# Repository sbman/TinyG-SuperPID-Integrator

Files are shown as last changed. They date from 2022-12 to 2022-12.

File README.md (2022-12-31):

# TinyG-SuperPID-Integrator
 A schematic and PCB design to integrate TinyG with SuperPID

# TinyG Settings
$p1                                                                    
[p1frq] pwm frequency               100 Hz
[p1csl] pwm cw speed lo            5000 RPM
[p1csh] pwm cw speed hi           30000 RPM
[p1cpl] pwm cw phase lo           0.833 [0..1]
[p1cph] pwm cw phase hi           0.000 [0..1]
[p1wsl] pwm ccw speed lo           1000 RPM
[p1wsh] pwm ccw speed hi           2000 RPM
[p1wpl] pwm ccw phase lo          0.125 [0..1]
[p1wph] pwm ccw phase hi          0.200 [0..1]
[p1pof] pwm phase off             0.833 [0..1]

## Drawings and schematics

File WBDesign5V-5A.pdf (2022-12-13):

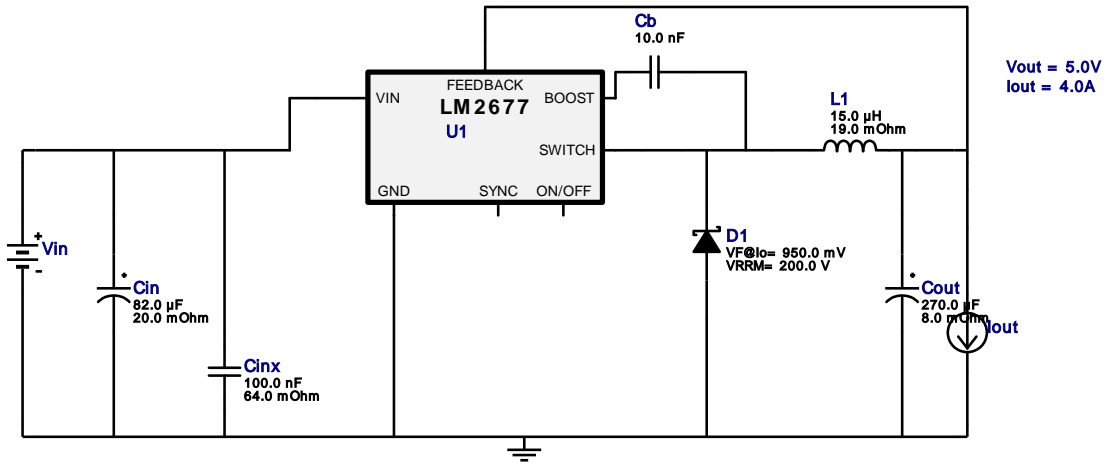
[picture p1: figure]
LM 2 6 7 7 VIN; FEEDBACK; BOOST; SWITCH; GND; SYNC ON/OFF; Cin 82.0 µF 20.0 m Ohm; Cinx 100.0 nF 64.0 m Ohm; Vout = 5.0V Iout = 4.0A; Cout 270.0 µF 8.0 m Ohm; D1 VF@Io= 950.0 m V VRRM= 200.0 V; L1 15.0 µH 19.0 m Ohm; Vin; Iout

Copyright © 2022, Texas Instruments Incorporated | 1 | ti.com/webench

WEBENCH®
Design Report LM2677SX-5.0/NOPB : LM2677SX-5.0/ NOPB 18V-26V to 5.00V @ 4A December 12, 2022 17:42:08 GMT-06:00

## WEBENCH ® Design Report

Design : 14 LM2677SX-5.0/NOPB
LM2677SX-5.0/NOPB 18V-26V to 5.00V @ 4A

VinMin = 18.0V
VinMax = 26.0V
Vout = 5.0V
Iout = 4.0A

Device = LM2677SX-5.0/NOPB Topology = Buck
Created = 2022-12-12 16:49:55.899 BOM Cost = $5.68
BOM Count = 7
Total Pd = 4.2W
1. The small series "trace inductance", particularly from the Switch Output pin, can create a high frequency (10's of MHz) ringing signal at the switch output. If problematic, this ringing can be reduced or eliminated by the use of a series RC damper or snubber network from the switch output to ground. Values of 0.01 uF and 10 ohm are good starting values that may need to be varied depending on the magnitude of parasitic factors in a given design. In an actual end application, these components are normally not required if proper care to minimize trace lengths is taken in the PCB design.

## Electrical BOM

Name | Manufacturer | Part Number | Properties | Qty Price | Footprint
Cb | TDK | CGA4C2C0G1H103J060AA (https://product.tdk.com/en/search/capacitor/ceramic/mlcc/info?part%5Fno%3DCGA4C2C0G1H103J060AA) Series= C0G/NP0 | Cap= 10.0 nF VDC= 50.0 V IRMS= 0.0 A
1 | $0.06
| | | | | 0805 7 mm²
Cin | Panasonic | 35SVPF82M Series= SVPF | Cap= 82.0 uF ESR= 20.0 mOhm VDC= 35.0 V IRMS= 4.0 A
1 | $1.17

CAPSMT_62_E12 106 mm²
Cinx | Kemet | C0805C104M5RACTU (http://capacitoredge.kemet.com/capedge2/DataSheet/Datasheet%2DC0805C104M5RACTU.pdf?pn%3DC0805C104M5RACTU) Series= X7R

Cap= 100.0 nF
ESR= 64.0 mOhm
VDC= 50.0 V
IRMS= 1.64 A

1 $0.01
0805 7 mm²
Cout | Panasonic | 16SVPG270M Series= SVPG | Cap= 270.0 uF ESR= 8.0 mOhm VDC= 16.0 V IRMS= 5.8 A
1 | $0.97

CAPSMT_62_C10 74 mm²
D1 | SMC Diode Solutions | SBRD10200TR (http://www.smc%2Ddiodes.com/propdf/SBRD10200%20N1314%20REV.%2D.pdf) | VF@Io= 950.0 mV VRRM= 200.0 V
1 | $0.18

DPAK 102 mm²

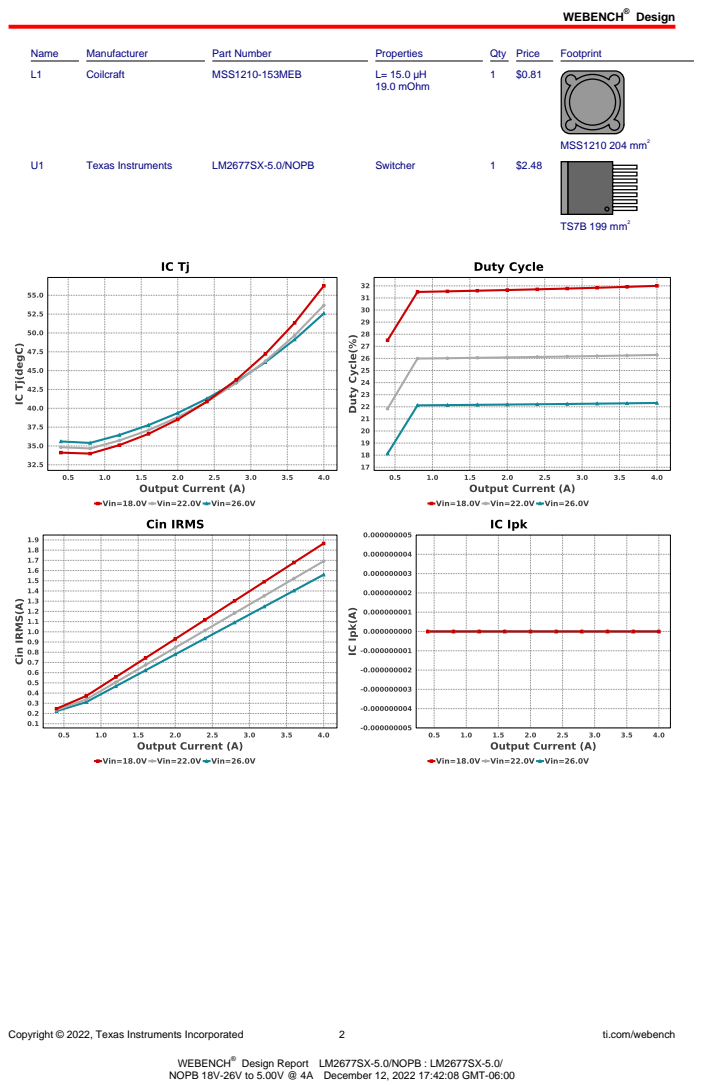
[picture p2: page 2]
Design; Copyright © 2022, Texas Instruments Incorporated; ti.com/webench; Name; Manufacturer; Part Number; Properties; Qty Price; Footprint; Coilcraft; MSS1210-153MEB; 19.0 mOhm; MSS1210 204 mm²; Texas Instruments; LM2677SX-5.0/NOPB; Switcher; TS7B 199 mm²

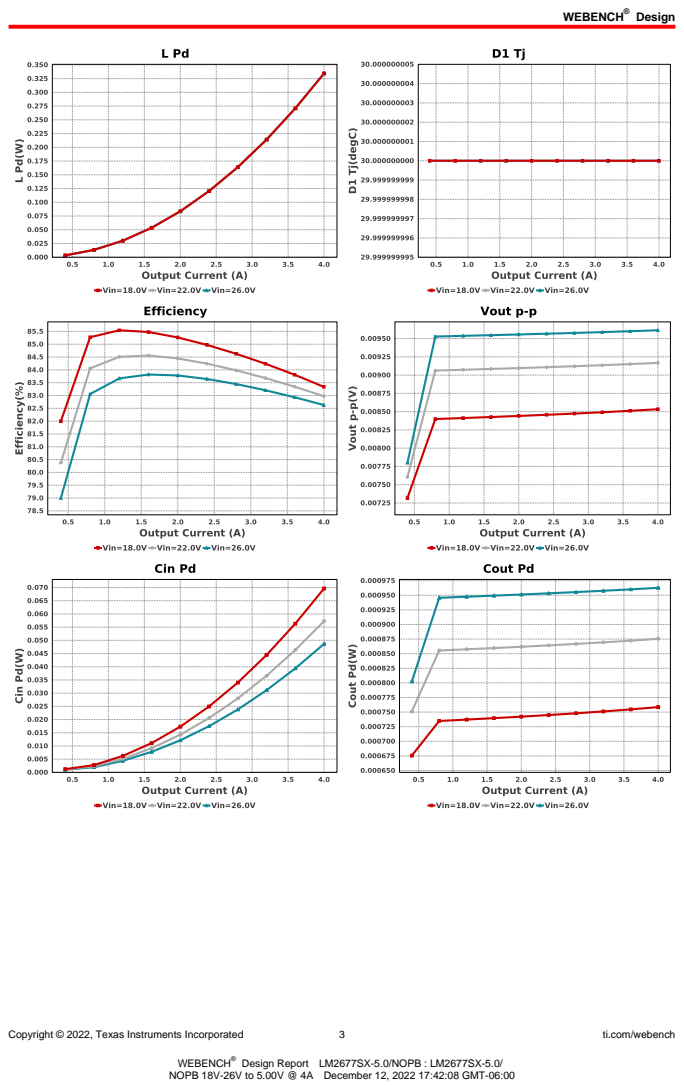
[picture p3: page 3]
Copyright © 2022, Texas Instruments Incorporated; ti.com/webench

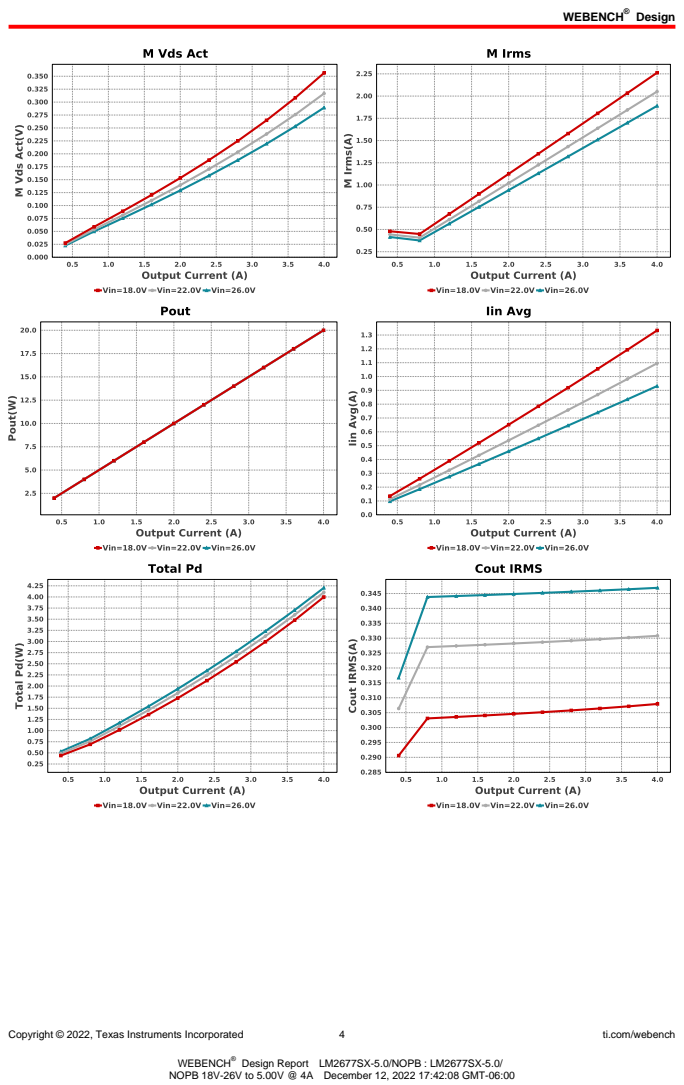
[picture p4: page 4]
Copyright © 2022, Texas Instruments Incorporated; ti.com/webench

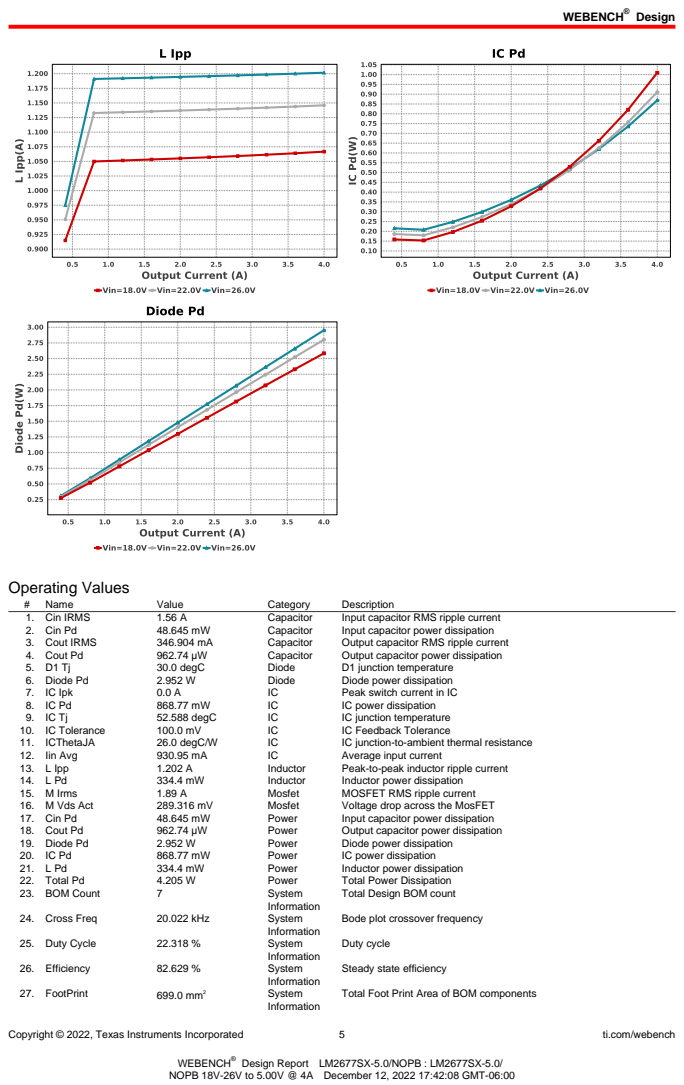
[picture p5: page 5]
Copyright © 2022, Texas Instruments Incorporated; ti.com/webench; Operating Values; Name; Value; Category; Description; 1. Cin IRMS; Capacitor; Input capacitor RMS ripple current; 2. Cin Pd; Input capacitor power dissipation; 3. Cout IRMS; Output capacitor RMS ripple current; 4. Cout Pd; Output capacitor power dissipation; 30.0 degC; Diode; D1 junction temperature; 6. Diode Pd; Diode power dissipation; 7. IC Ipk; Peak switch current in IC; IC power dissipation; 52.588 degC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

Total Design BOM count

Bode plot crossover frequency

Steady state efficiency

Total Foot Print Area of BOM components

Copyright © 2022, Texas Instruments Incorporated | 6 | ti.com/webench
# | Name | Value | Category | Description

28. Frequency | 260.0 kHz | System
| | | Information | Switching frequency
29. Iout | 4.0 A | System
| | | Information | Iout operating point
30. Mode | CCM | System
| | | Information | Conduction Mode
31. Phase Marg | 57.264 deg | System
| | | Information | Bode Plot Phase Margin
32. Pout | 20.0 W | System
| | | Information | Total output power
33. Total BOM | $5.68 | System
| | | Information | Total BOM Cost
34. Vin | 26.0 V | System
| | | Information | Vin operating point
35. Vout | 5.0 V | System
| | | Information | Operational Output Voltage
36. Vout Tolerance | 2.0 % | System
| | | Information | Vout Tolerance based on IC Tolerance (no load) and voltage divider resistors if applicable
37. Vout p-p | 9.614 mV | System
| | | Information | Peak-to-peak output ripple voltage
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

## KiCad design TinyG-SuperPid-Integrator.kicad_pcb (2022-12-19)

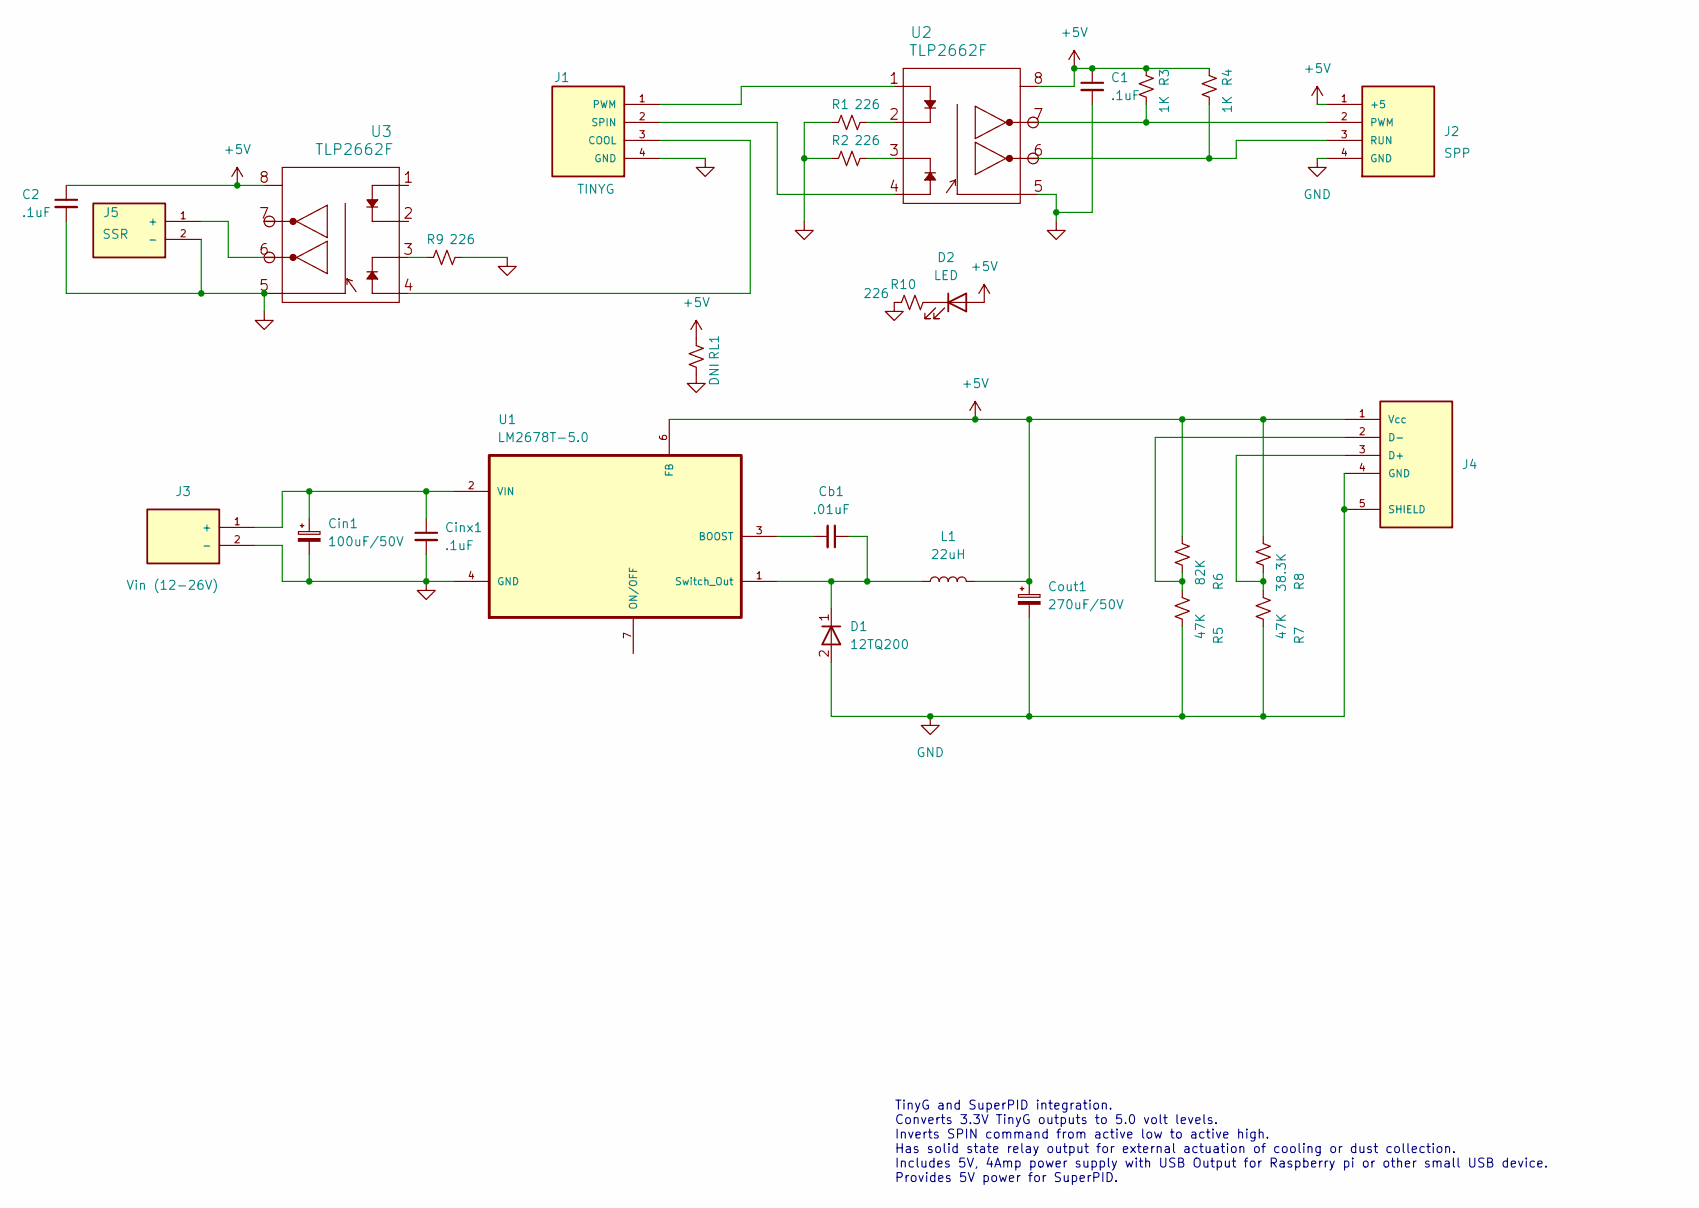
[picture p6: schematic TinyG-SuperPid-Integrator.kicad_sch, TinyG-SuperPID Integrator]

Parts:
C1, C2: .1uF; C_Disc_D3.8mm_W2.6mm_P2.50mm; Digikey 445-173588-1-ND
Cb1: .01uF; C_Disc_D3.8mm_W2.6mm_P2.50mm; Digikey 445-173172-1-ND
Cin1: 100uF/50V; CP_Radial_D8.0mm_P3.50mm; Digikey 399-6119-ND
Cinx1: .1uF; C_Disc_D3.8mm_W2.6mm_P2.50mm; Digikey 445-173588-1-ND
Cout1: 270uF/50V; CP_Radial_D10.0mm_P5.00mm; Digikey 399-ESY277M050AH4AA-ND
D1: 12TQ200; TO-220-2_Vertical; Digikey 1655-1003-ND
D2: LED; LED_D5.0mm
J1: TINYG; CUI_TB001-500-04BE; Digikey 102-6136-ND
J2: SPP; CUI_TB001-500-04BE; Digikey 102-6136-ND
J3: Vin (12-26V); CUI_TB001-500-02BE; Digikey 102-6134-ND
J4: UJ2-AH-4-TH; CUI_UJ2-AH-4-TH; PART_REV 1.0; Digikey 102-3994-ND
J5: SSR; CUI_TB001-500-02BE; Digikey 102-6134-ND
L1: 22uH; L_Radial_D16.8mm_P12.07mm_Vishay_IHB-1; Digikey 732-7163-ND
R1, R2, R9, R10: 226; MRS25000C2260FCT00; Digikey BC4072CT-ND
R3, R4: 1K; MRS25000C2260FCT00; Digikey BC3325CT-ND
R5, R7: 47K; MRS25000C2260FCT00; Digikey BC4178CT-ND
R6: 82K; MRS25000C2260FCT00; Digikey BC4265CT-ND
R8: 38.3K; MRS25000C2260FCT00; Digikey BC4145CT-ND
RL1: DNI; R_Axial_DIN0309_L9.0mm_D3.2mm_P12.70mm_Horizontal; Digikey BC4072CT-ND
U1: LM2678T-5.0; TO127P457X1016X2052-7P; MPN LLM2678T-5.0
U2, U3: TLP2662F; Digikey TLP2662(F)-ND

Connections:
+5V: C1.1, C2.1, Cout1.1, D2.2 (A), J2.1 (+5), J4.1 (Vcc), L1.2, R3.2, R4.2, R6.2, R8.2, RL1.2, U1.6 (FB), U2.8 (Vcc), U3.8 (Vcc)
GND: C1.2, C2.2, Cin1.2, Cinx1.2, Cout1.2, D1.2 (A), J1.4 (GND), J2.4 (GND), J3.2 (-), J4.4 (GND), J4.5 (SHIELD), J5.2 (-), R1.2, R2.2, R5.1, R7.1, R9.1, R10.2, RL1.1, U1.4 (GND), U2.5 (GND), U3.5 (GND)
unnamed: Cb1.1, D1.1 (K), L1.1, U1.1 (Switch_Out)
unnamed: Cb1.2, U1.3 (BOOST)
unnamed: Cin1.1, Cinx1.1, J3.1 (+), U1.2 (VIN)
unnamed: D2.1 (K), R10.1
unnamed: J1.1 (PWM), U2.1 (A1)
unnamed: J1.2 (SPIN), U2.4 (A2)
unnamed: J1.3 (COOL), U3.4 (A2)
unnamed: J2.2 (PWM), R3.1, U2.7 (O1)
unnamed: J2.3 (RUN), R4.1, U2.6 (O2)
unnamed: J4.2 (D-), R5.2, R6.1
unnamed: J4.3 (D+), R7.2, R8.1
unnamed: J5.1 (+), U3.6 (O2)
unnamed: R1.1, U2.2 (C1)
unnamed: R2.1, U2.3 (C2)
unnamed: R9.2, U3.3 (C2)

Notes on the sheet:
TinyG and SuperPID integration. Converts 3.3V TinyG outputs to 5.0 volt levels. Inverts SPIN command from active low to active high. Has solid state relay output for external actuation of cooling or dust collection. Includes 5V, 4Amp power supply with USB Output for Raspberry pi or other small USB 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

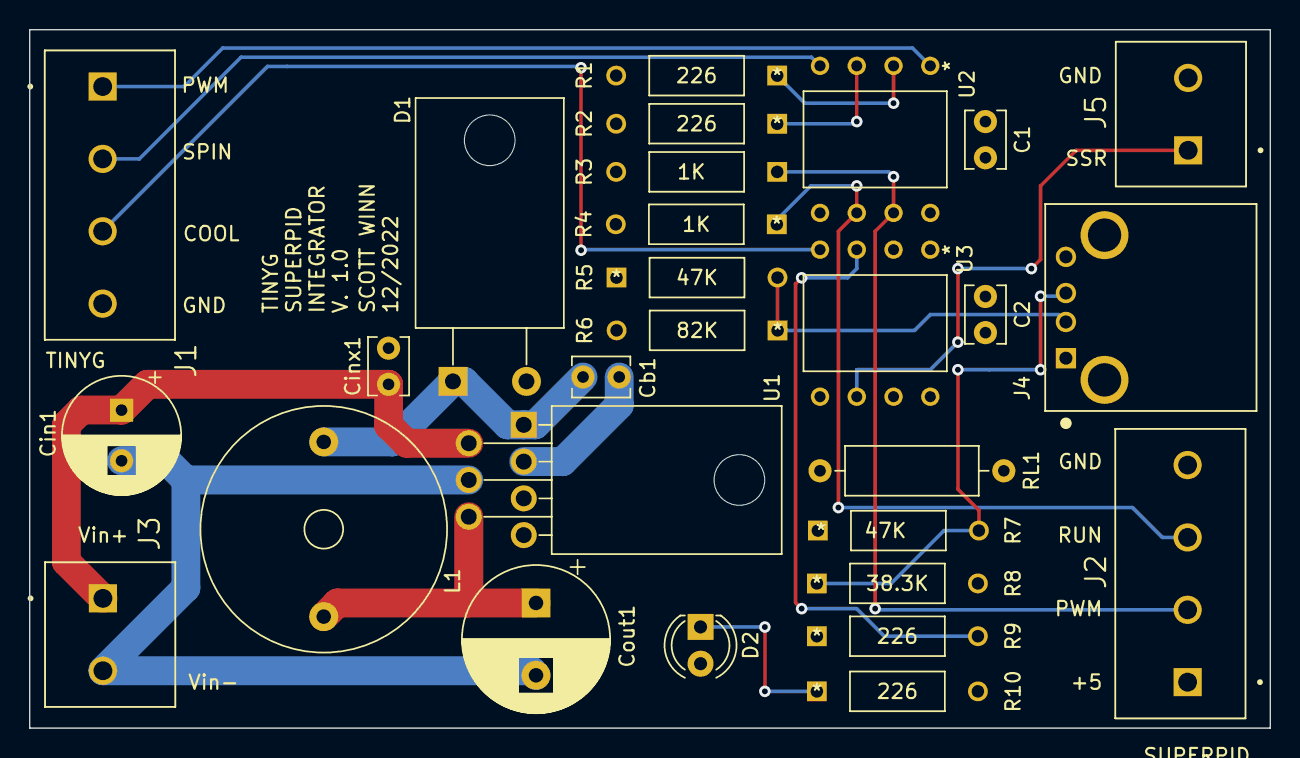
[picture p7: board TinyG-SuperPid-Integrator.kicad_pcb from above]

Board: 4 copper layers, 85.7 x 48.3 mm, 28 parts (0 on the bottom side), 17 nets.

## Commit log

2022-12-13 Initial commit
    Incomplete, need USB connector.
    [TinyG-SuperPid-Integrator.kicad_pcb, TinyG-SuperPid-Integrator.kicad_sch]
2022-12-13 Completed schematic, first Rev of PCB layout complete.
    PCB Layout complete
    [TinyG-SuperPid-Integrator.kicad_pcb, TinyG-SuperPid-Integrator.kicad_sch]
2022-12-14 Fixed backwards diode on U2, straightened internal plane boundaries (aesthetic)
    [TinyG-SuperPid-Integrator.kicad_pcb, TinyG-SuperPid-Integrator.kicad_sch]
2022-12-14 Added power LED, load resistor. Updated power supply layout.
    Updated layout of power supply to shorten distances between L1, Cout, Cin, and Cb1. Added power LED indicator and pads for a small load resistor to stabilize the switching PS if needed.
    [TinyG-SuperPid-Integrator.kicad_pcb, TinyG-SuperPid-Integrator.kicad_sch]
2022-12-19 Updated layout of PS, generated Gerber output
    PCB Update, gerber files
    [TinyG-SuperPid-Integrator-B_Adhesive.gbr, TinyG-SuperPid-Integrator-B_Cu.gbr, TinyG-SuperPid-Integrator-B_Mask.gbr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]

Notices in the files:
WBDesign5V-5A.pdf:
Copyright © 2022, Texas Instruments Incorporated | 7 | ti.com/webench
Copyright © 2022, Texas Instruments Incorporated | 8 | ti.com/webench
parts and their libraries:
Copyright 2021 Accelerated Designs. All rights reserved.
